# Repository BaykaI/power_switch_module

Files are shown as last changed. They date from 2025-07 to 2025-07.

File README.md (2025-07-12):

# power_switch_module
Разработана плата модуля ключа питания для устройств PCIe.
ТЗ:
Входное питание стандарта ATX 12В.;
Питание со входного разъёма ATX-PCIe-8pin;
Управление через интерфейс RS485 по протоколу ModBus;
Для подключения управления использовались разъёмы 4P4C в количестве 2 шт., соединённые параллельно для объединения нескольких модулей в цепочку;
Терминирование RS485 через джампер (3pin, дабы не потерять сам джампер);
измерение тока нагрузки;
измерение напряжения на входе и выходе;
Входной разъём типа Male, выходной - Female.
В данной задаче делалсь структурная и принципиальная схемы, топология.

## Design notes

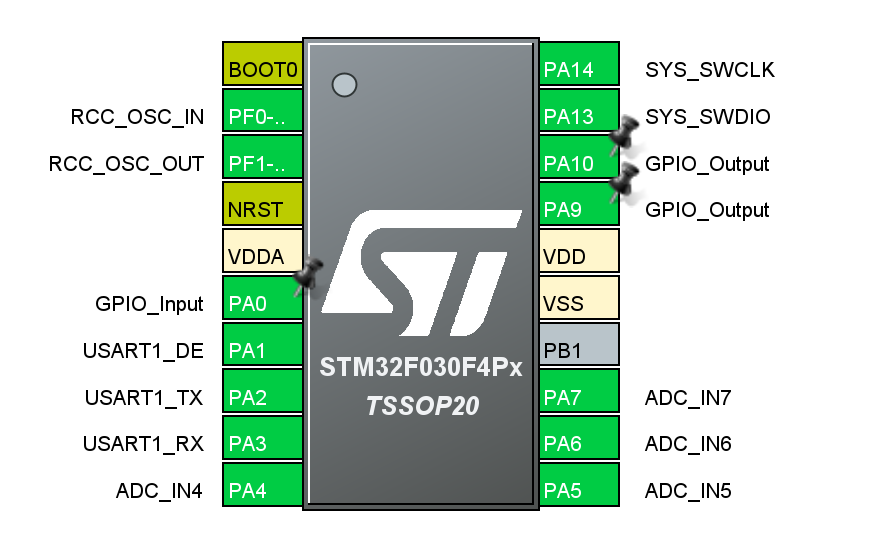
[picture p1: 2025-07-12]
Снимок экрана 2025-07-08 010331.png

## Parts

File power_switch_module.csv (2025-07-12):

 Reference  Value  Qty  DNP
 C1,C2,C3,C7,C8,C10  GRM033R60J105MEA2  6
 C4,C5  GRM1555C1H200JA01D  2
 C6,C11,C12  CL05A106MQ5NUNC  3
 C9  GRM31CR71E106KA12L  1
 C13  GRM188R61A226ME15D  1
 DA1  BTS6143D  1
 DA2  TPT75176H-VS1R  1
 DA3  K7803MT-500R4  1
 DD1  STM32F030F4P6  1
 DD2  TXU0104RUT  1
 H1  M3_ISO7380  1
 HL1,HL2  LTST-C295KGKRKT  2
 JP2  PinHeader  3x1  2.54mm  Vertical  1
 R1,R5,R8,R9  RC0402FR-0710KL  4
 R2,R3,R10  RC0402FR-071KL  3
 R4  RC0402FR-0710KL  1  DNP
 R6  RC0402FR-07750L  1
 R7  RC0402FR-07160L  1
 R11,R12,R13,R14  RC0603FR-07150RPL  4
 R15  RC0402FR-07120L  1
 R16  RC0402FR-07100KL  1
 R17  RC0402FR-0747KL  1  DNP
 R18  RC0402FR-0715KL  1  DNP
 S1  KLS7-TS3601-4.3-180  1
 VT1  IRLML2502  1
 X1,X2  0039301080  2
 X3  PinHeader  4x1  2.54mm  Vertical  1
 X4,X5  L-KLS12-123-4P4C-W/O-1-01  2
 ZQ1  FC4SDCBMF8.0-T1  1

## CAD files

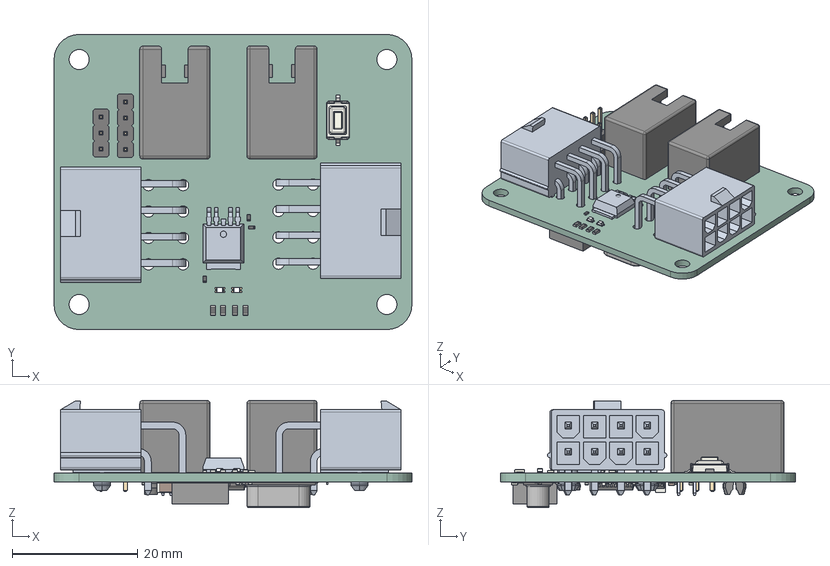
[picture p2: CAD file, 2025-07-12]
project_kicad/power_switch_module.step
57.0 x 47.0 x 17.1 mm
R_0603_1608Metric x 4
87180044LF x 2
PinHeader_1x03_P2.54mm_Vertical
SW_Tactile_SPST_NO_Straight_CK_PTS636Sx25SMTRLFS
R_0402_1005Metric x 14
LTST-C295KGKRKT x 2
power_switch_module 1.13.1
PinHeader_1x04_P2.54mm_Vertical
C_0201_0603Metric x 9
Crystal_SMD_HC49-SD
C_0402_1005Metric x 3
SOT-23
TSSOP-20_4.4x6.5mm_P0.65mm
C_1206_3216Metric
Pins
MSOP-8_3x3mm_P0.65mm
TXU0104RUTR--3DModel-STEP-56544
power_switch_module_PCB

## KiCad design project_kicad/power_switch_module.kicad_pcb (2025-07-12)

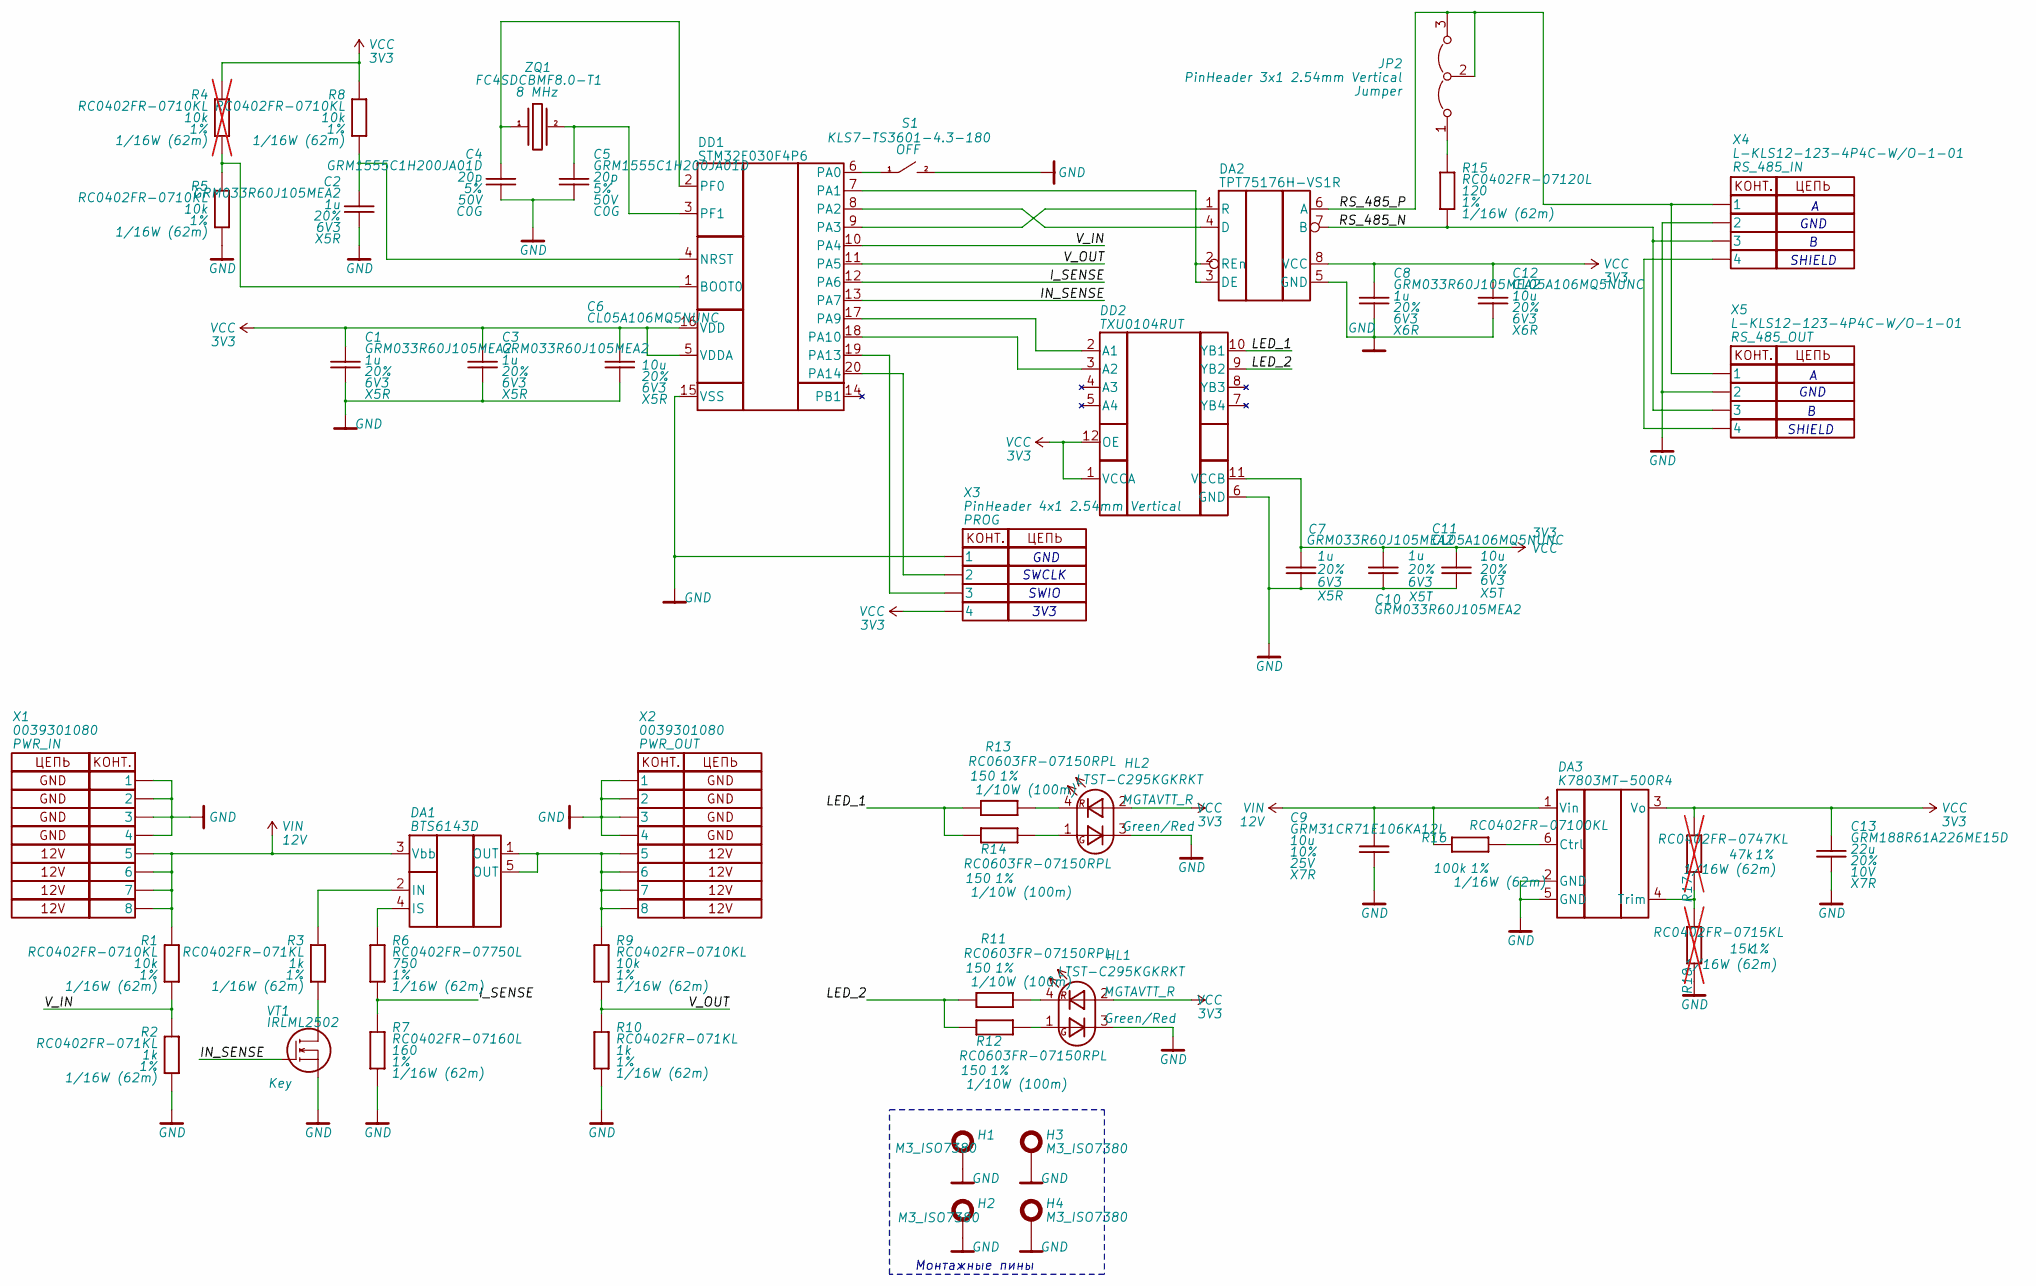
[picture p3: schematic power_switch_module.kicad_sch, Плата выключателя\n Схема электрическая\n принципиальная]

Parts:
C1, C2, C3, C7, C8, C10: GRM033R60J105MEA2; C_0201_0603Metric; Tolerance 20%
C4, C5: GRM1555C1H200JA01D; C_0201_0603Metric; Tolerance 5%
C6, C11, C12: CL05A106MQ5NUNC; C_0402_1005Metric; Tolerance 20%
C9: GRM31CR71E106KA12L; C_1206_3216Metric; Tolerance 10%
C13: GRM188R61A226ME15D; C_0201_0603Metric; Tolerance 20%
DA1: BTS6143D; TO-252-4
DA2: TPT75176H-VS1R; MSOP-8_3x3mm_P0.65mm
DA3: K7803MT-500R4; K7803MT-500R4_1
DD1: STM32F030F4P6; TSSOP-20_4.4x6.5mm_P0.65mm
DD2: TXU0104RUT; UQFN-12
H1, H2, H3, H4: M3_ISO7380; MountingHole_3.2mm_M3_ISO7380_Pad
HL1, HL2: LTST-C295KGKRKT; LTST-C295
JP2: PinHeader 3x1 2.54mm Vertical; PinHeader_1x03_P2.54mm_Vertical
R1, R5, R8, R9: RC0402FR-0710KL; R_0402_1005Metric; Tolerance 1%
R2, R3, R10: RC0402FR-071KL; R_0402_1005Metric; Tolerance 1%
R4: RC0402FR-0710KL; R_0402_1005Metric; Tolerance 1%; not fitted
R6: RC0402FR-07750L; R_0402_1005Metric; Tolerance 1%
R7: RC0402FR-07160L; R_0402_1005Metric; Tolerance 1%
R11, R12, R13, R14: RC0603FR-07150RPL; R_0603_1608Metric; Tolerance 1%
R15: RC0402FR-07120L; R_0402_1005Metric; Tolerance 1%
R16: RC0402FR-07100KL; R_0402_1005Metric; Tolerance 1%
R17: RC0402FR-0747KL; R_0402_1005Metric; Tolerance 1%; not fitted
R18: RC0402FR-0715KL; R_0402_1005Metric; Tolerance 1%; not fitted
S1: KLS7-TS3601-4.3-180; SW_Tactile_SPST_NO_Straight_CK_PTS636Sx25SMTRLFS
VT1: IRLML2502; SOT-23
X1, X2: 0039301080; Molex_Mini-Fit_Jr_5569-08A2_2x04_P4.20mm_Horizontal
X3: PinHeader 4x1 2.54mm Vertical; PinHeader_1x04_P2.54mm_Vertical
X4, X5: L-KLS12-123-4P4C-W/O-1-01; RJ9_Evercom_5301-440xxx_Horizontal
ZQ1: FC4SDCBMF8.0-T1; Crystal_SMD_HC49-SD

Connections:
/IN_SENSE: DD1.13 (PA7), VT1.1
/I_SENSE: DD1.12 (PA6), R6.1, R7.2
/LED_1: DD2.10 (YB1), R13.2, R14.2
/LED_2: DD2.9 (YB2), R11.2, R12.2
/RS_485_N: DA2.7 (B), R15.1, X4.3, X5.3
/RS_485_P: DA2.6 (A), JP2.2 (C), JP2.3 (B), X4.1, X5.1
/V_IN: DD1.10 (PA4), R1.1, R2.2
/V_OUT: DD1.11 (PA5), R9.1, R10.2
GND: C1.2, C2.2, C3.2, C4.2, C5.2, C6.2, C7.2, C8.2, C9.2, C10.2, C11.2, C12.2, C13.2, DA2.5 (GND), DA3.2 (GND), DA3.5 (GND), DD1.15 (VSS), DD2.6 (GND), H1.1, H2.1, H3.1, H4.1, HL1.3 (K1), HL2.3 (K1), R2.1, R5.1, R7.1, R10.1, R18.2, S1.2, VT1.2, X1.1, X1.2, X1.3, X1.4, X2.1, X2.2, X2.3, X2.4, X3.1, X4.2, X5.2; also elsewhere on the board
unnamed: DA1.2 (IN), R3.2
unnamed: DA1.4 (IS), R6.2
unnamed 11: DA1.1 (OUT), DA1.5 (OUT), R9.2, X2.5, X2.6, X2.7, X2.8; also elsewhere on the board
unnamed: DA2.4 (D), DD1.8 (PA2)
unnamed: DA2.2 (REn), DA2.3 (DE), DD1.7 (PA1)
unnamed: DA2.1 (R), DD1.9 (PA3)
unnamed: DA3.6 (Ctrl), R16.1
unnamed: DA3.4 (Trim), R17.2, R18.1
unnamed: DD1.1 (BOOT0), R4.1, R5.2
unnamed: C2.1, DD1.4 (NRST), R8.1
unnamed: DD1.6 (PA0), S1.1
unnamed: DD1.17 (PA9), DD2.2 (A1)
unnamed: DD1.18 (PA10), DD2.3 (A2)
unnamed: DD1.19 (PA13), X3.3
unnamed: DD1.20 (PA14), X3.2
unnamed: C4.1, DD1.2 (PF0), ZQ1.1
unnamed: C5.1, DD1.3 (PF1), ZQ1.2
unnamed: HL1.1 (A1), R12.1
unnamed: HL1.4 (K2), R11.1
unnamed: HL2.1 (A1), R14.1
unnamed: HL2.4 (K2), R13.1
unnamed: JP2.1 (A), R15.2
unnamed: R3.1, VT1.3
unnamed: X4.4, X5.4
VCC: C1.1, C3.1, C6.1, C7.1, C8.1, C10.1, C11.1, C12.1, C13.1, DA2.8 (VCC), DA3.3 (Vo), DD1.5 (VDDA), DD1.16 (VDD), DD2.1 (VCCA), DD2.11 (VCCB), DD2.12 (OE), HL1.2 (A2), HL2.2 (A2), R4.2, R8.2, R17.1, X3.4
VIN: C9.1, DA1.3 (Vbb), DA3.1 (Vin), R1.2, R16.2, X1.5, X1.6, X1.7, X1.8; also elsewhere on the board

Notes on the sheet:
SHIELD
GND
3V3
Монтажные пины
SWIO
SWCLK

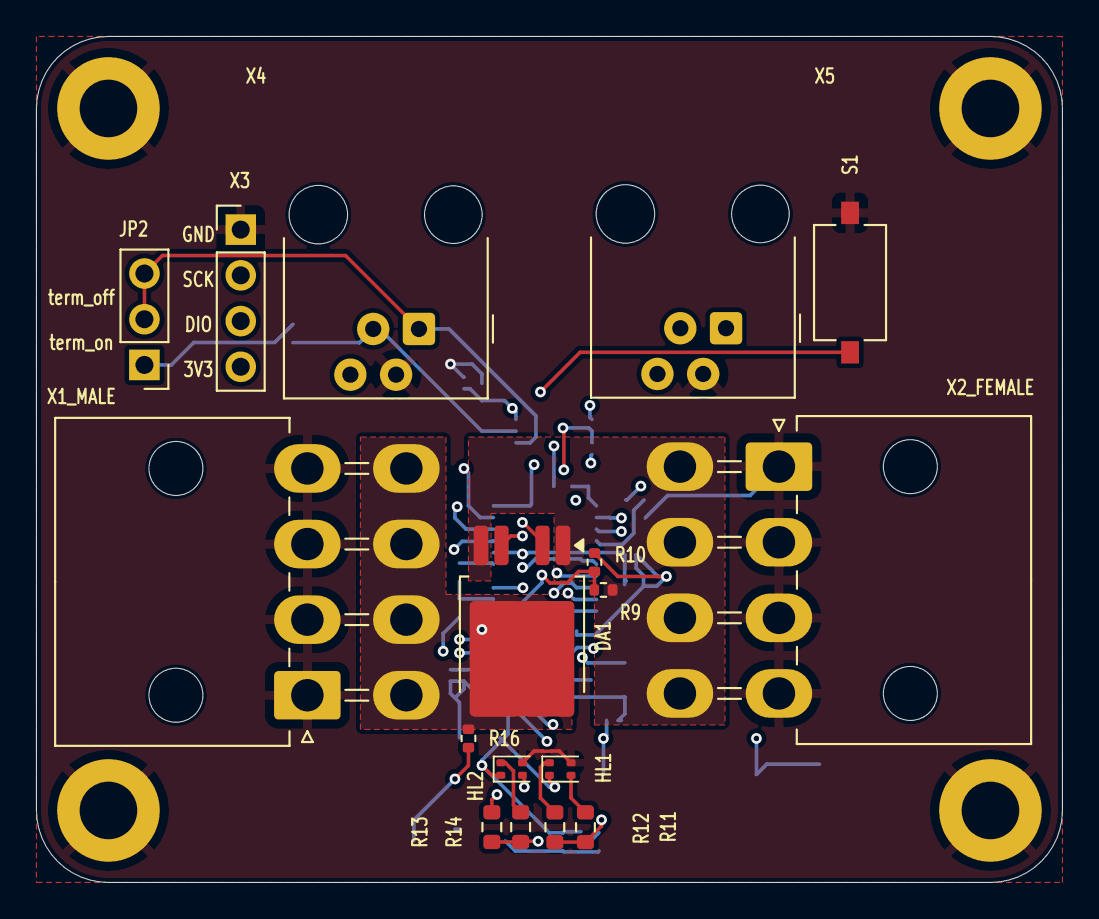
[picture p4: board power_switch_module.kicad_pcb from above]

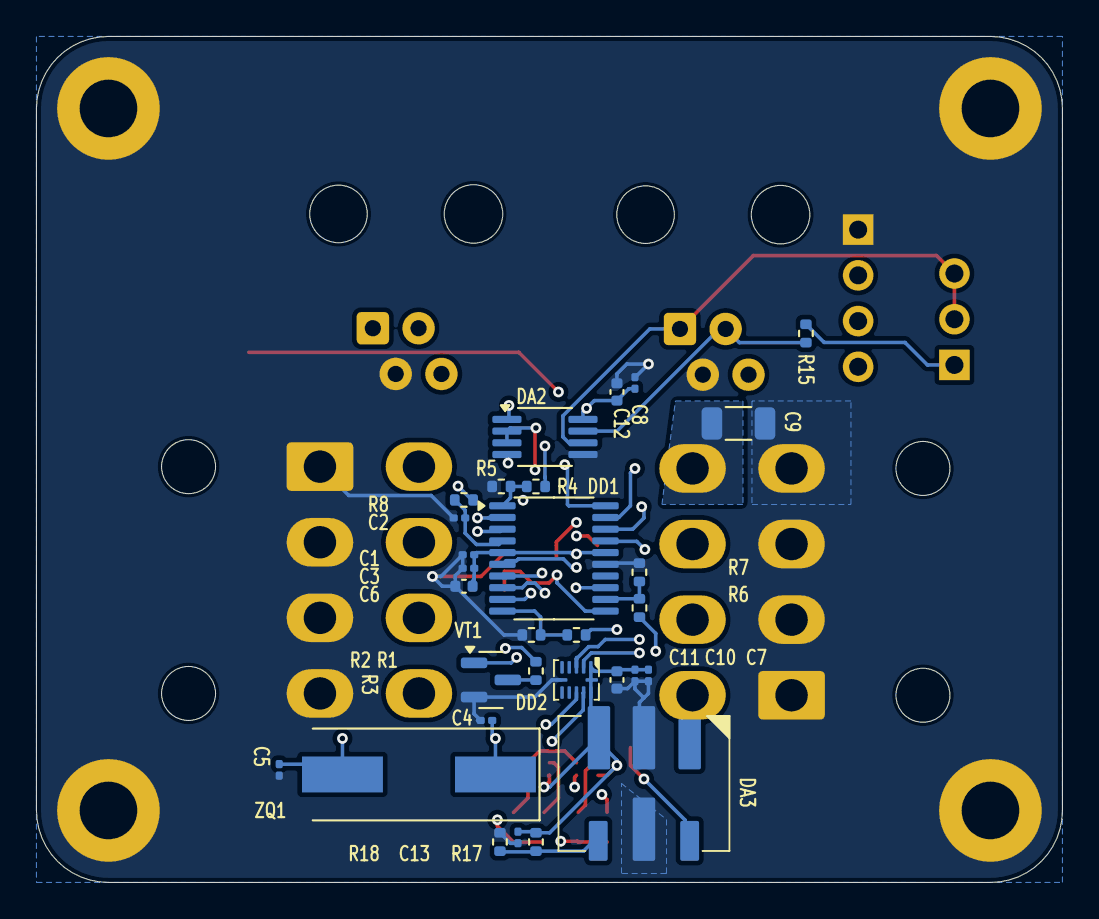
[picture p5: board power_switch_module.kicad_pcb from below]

Board: 4 copper layers, 57.0 x 47.0 mm, 51 parts (30 on the bottom side), 35 nets.

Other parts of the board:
X1_MALE, X2_FEMALE: 0039301080; Molex_Mini-Fit_Jr_5569-08A2_2x04_P4.20mm_Horizontal

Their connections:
GND: X1_MALE.1, X1_MALE.2, X1_MALE.3, X1_MALE.4, X2_FEMALE.1, X2_FEMALE.2, X2_FEMALE.3, X2_FEMALE.4; also elsewhere on the board
unnamed 11: X2_FEMALE.5, X2_FEMALE.6, X2_FEMALE.7, X2_FEMALE.8; also elsewhere on the board
VIN: X1_MALE.5, X1_MALE.6, X1_MALE.7, X1_MALE.8; also elsewhere on the board
